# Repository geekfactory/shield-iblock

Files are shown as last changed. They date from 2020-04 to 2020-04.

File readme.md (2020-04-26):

# Shield iBlock

Shield para Arduino Uno R3 (y tarjetas que comparten las mismas dimensiones) que permite conectar módulos y accesorios compatibles con el sistema iBlock desarrollado por Geek Factory.

Este shield "exporta" los puertos de la tarjeta Arduino Uno a cables planos de 10 hilos que pueden usarse para interconectar con otros módulos o el protoboard.

El sistema iBlock esta diseñado para usarse durante el aprendizaje de sistemas digitales programables o para desarrollar aplicaciones finales.

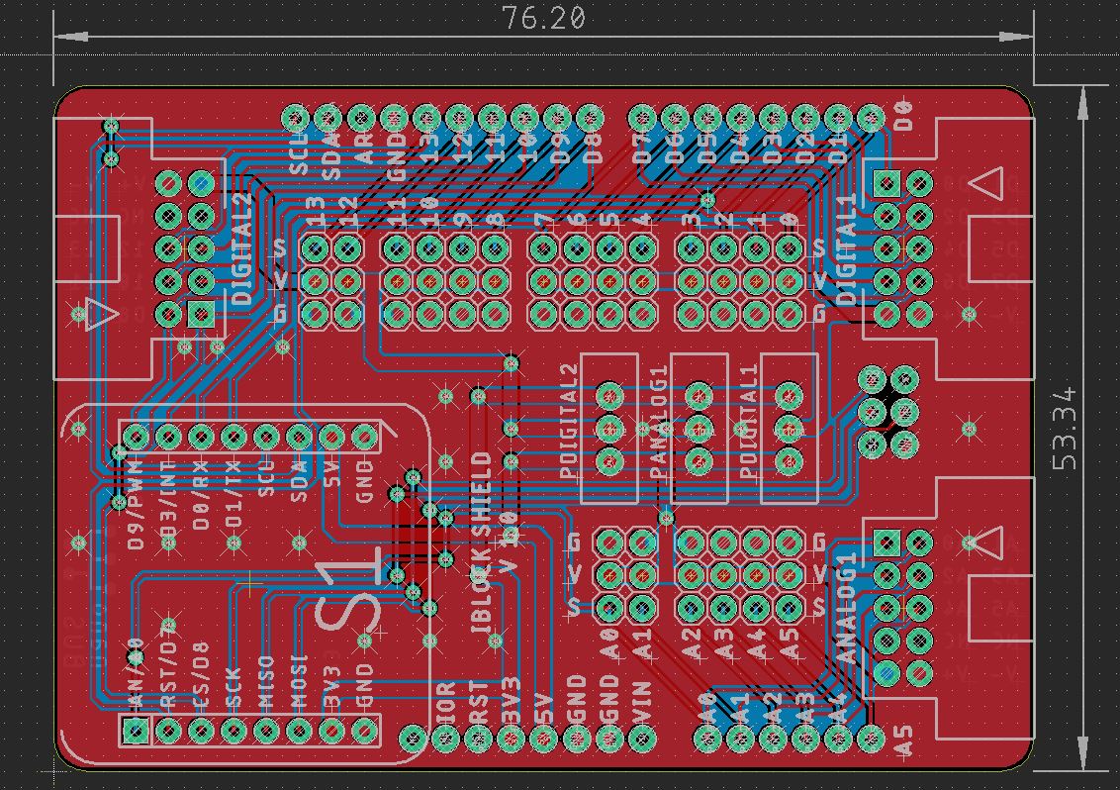
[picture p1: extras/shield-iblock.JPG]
Shield ioBlock


## Sistema iBlock

Se trata de una solución de conectividad diseñada para facilitar la reutilización de hardware en prototipos y sistemas realizados para producción. Esta basada en el uso de conectores [IDC (Insulation Displacement Connector)](https://en.wikipedia.org/wiki/Insulation-displacement_connector) y cable plano.

Principalmente se contempla el uso de conectores de 10 pines que permoiten llevar 8 bits o pines de I/O de propósito general y además la tierra y el voltaje de alimentación.

En este sistema cada uno de los módulos se diseñan con una distribución de pines conocida, de forma que sea posible intercambiar y reutilizar el hardware según las necesidades del proyecto.

La distribución de pines en el conector IDC-10 es la siguiente:

1. D0
2. D1
3. D2
4. D3
5. D4
6. D5
7. D6
8. D7
9. GND
10. V+ (3.3 o 5 volts)

Como el arduino Uno dispone de más puertos digitales, se continua en otro conector:

1. D8
2. D9
3. D10
4. D11
5. D12
6. D13
7. NC (sin conexión)
8. NC (sin conexión)
9. GND
10. V+ (3.3 o 5 volts)

La distribución es similar para los pines analógicos de la tarjeta.

## Periféricos y características

* 3 conectores IDC-10 que exponen todos los puertos digitales y analógicos de la tarjeta arduino
	* DIGITAL1 - Expone los pines del 0 al 7 digitales
	* DIGITAL2 - Expone los pines del 8 al 13 digitales
	* ANALOG1 - Expone los pines A0 al A5 analógicos
* 20 conectores tipo servo que brindan acceso a la alimentación y a todas las señales (D0 - D13 y A0 - A5)
* Diseño apilable que permite colocar otros shields o accesorios arriba de esta placa, incluso el conector SPI (ISP) se replica a otros shields
* Se utilizan conectores IDC-10 en angulo que permite la conexión del cable plano cuando hay otro shield colocado encima
* Selección de voltaje de alimentación (3.3 volts o 5 volts) en cada uno de los conectores IDC-10 mediante interruptores
* Conector Nanobus que permite expandir la funcionalidad del shield con otros módulos desarrollados para este estándar
* Dimensiones del PCB: 76.2 mm x 53.34mm (3 x 2.1 pulgadas)

## Contenido del repositorio

1. __root__ - Archivos fuente de EAGLE para esta placa
2. __/documents__ - Documentación adicional, hojas de datos de componentes e instrucciones de ensamble
3. __/production__ - Histórico de gerbers enviados a producción
4. __/extras__ - Dibujos técnicos, imagehes, hardware de montaje adicional y diseños de accesorios relacionados
4. __/firmware__ - Si existe el firmware de prueba o definitivo de esta placa

## Licencia de uso

**Este proyecto se publica como hardware de codigo abierto. Favor de leer detenidamente el archivo license.md para información detallada de la licencia.**

**Reconocimiento-NoComercial-CompartirIgual 4.0 Internacional (CC BY-NC-SA 4.0)**

Esto es un resumen inteligible para humanos (y no un sustituto) de la licencia.

Usted es libre de:

* __Compartir__ — copiar y redistribuir el material en cualquier medio o formato
* __Adaptar__ — remezclar, transformar y crear a partir del material

El licenciador no puede revocar estas libertades mientras cumpla con los términos de la licencia.

Bajo las condiciones siguientes:

* __Reconocimiento__ — Debe reconocer adecuadamente la autoría, proporcionar un enlace a la licencia e indicar si se han realizado cambios. Puede hacerlo de cualquier manera razonable, pero no de una manera que sugiera que tiene el apoyo del licenciador o lo recibe por el uso que hace.

* __NoComercial__ — No puede utilizar el material para una finalidad comercial.

* __CompartirIgual__ — Si remezcla, transforma o crea a partir del material, deberá difundir sus contribuciones bajo la misma licencia que el original.

No hay restricciones adicionales — No puede aplicar términos legales o medidas tecnológicas que legalmente restrinjan realizar aquello que la licencia permite.

## Versiones del Hardware

* 1.0 - Versión inicial

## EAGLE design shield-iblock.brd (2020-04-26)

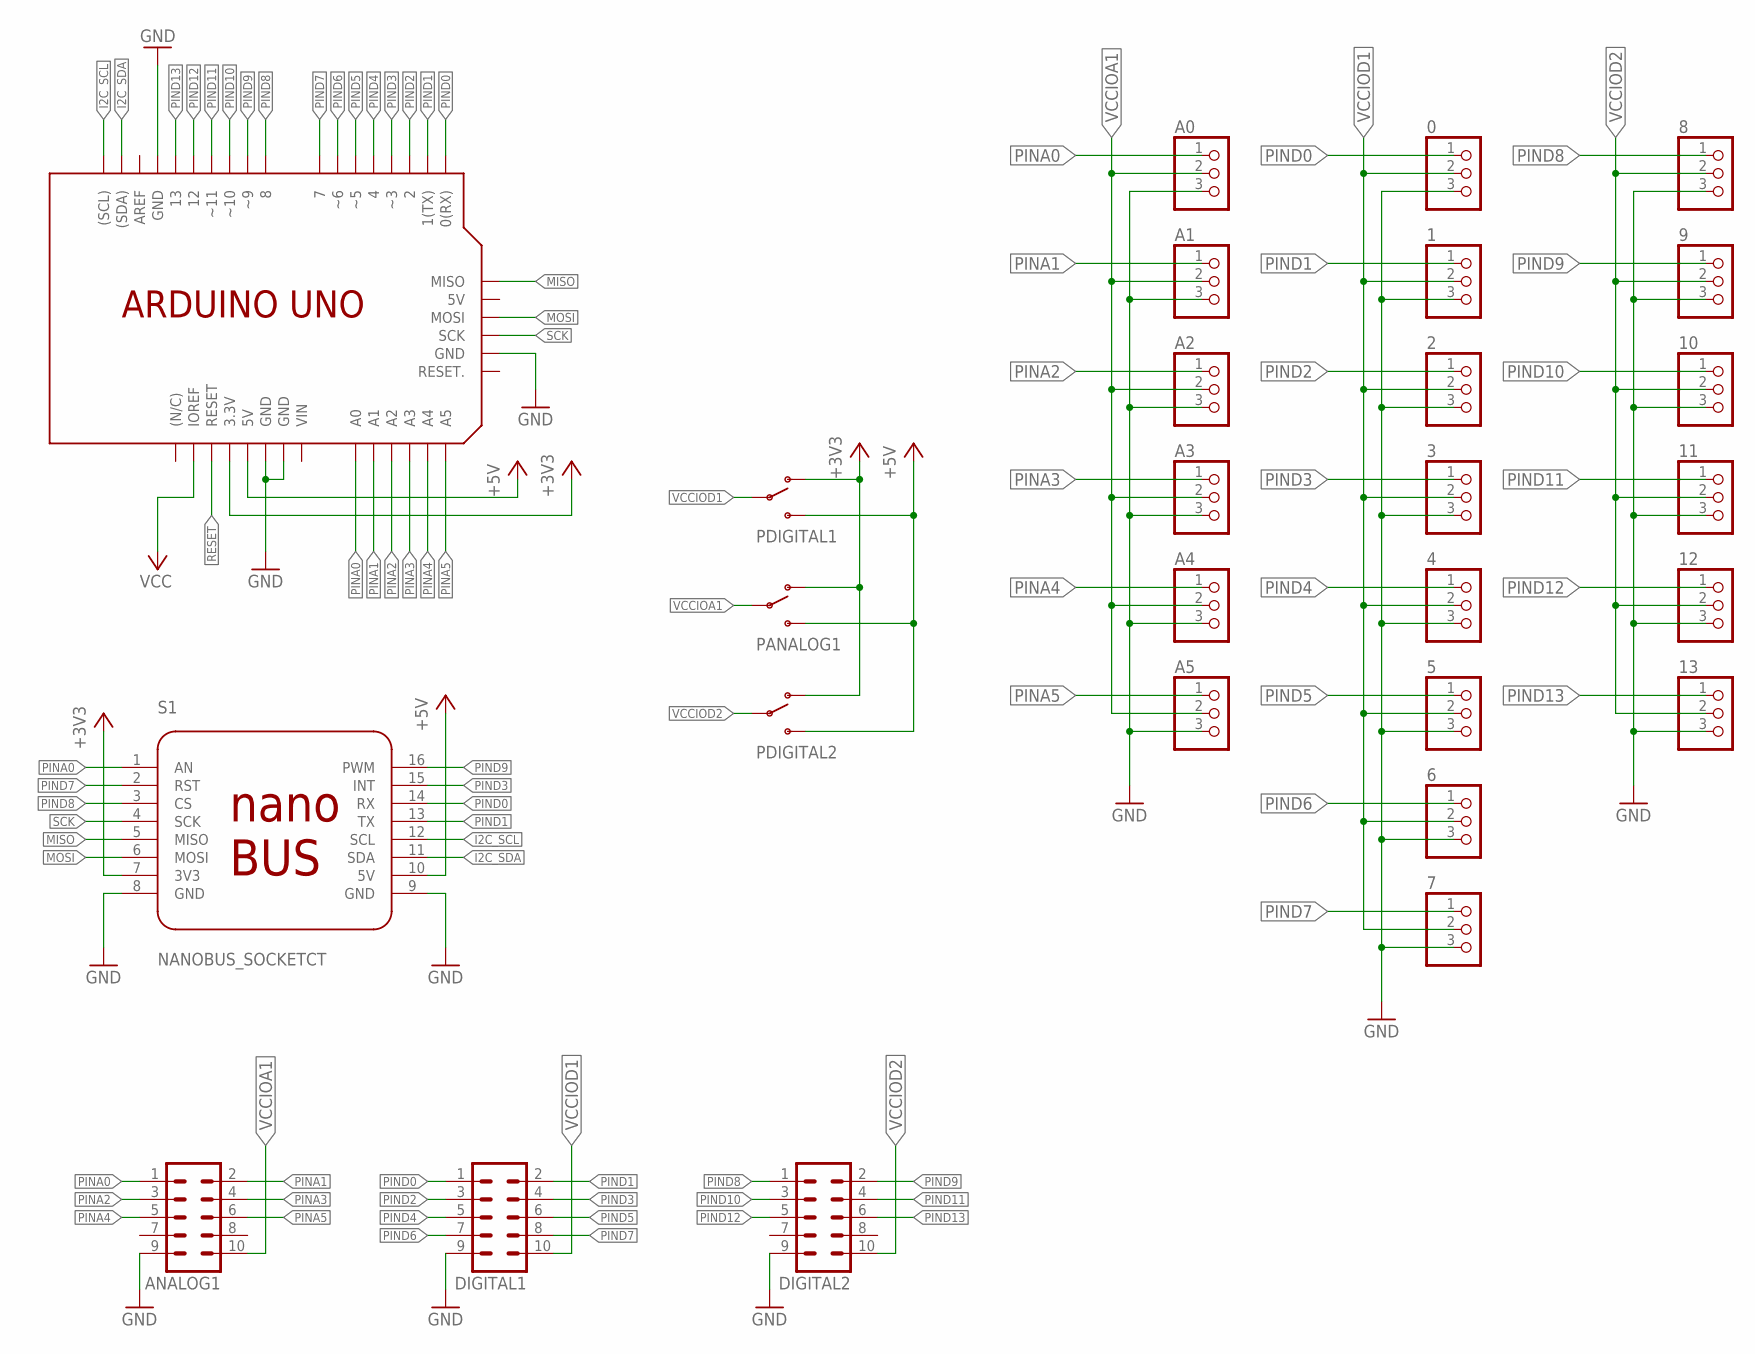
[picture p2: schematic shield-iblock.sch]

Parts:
0, 1, 2, 3, 4, 5, 6, 7, 8, 9, 10, 11, 12, 13: PINHD-1X3; 1X03
A0, A1, A2, A3, A4, A5: PINHD-1X3; 1X03
ANALOG1: MA05-2A
ARDUINO1: ARDUINO_UNO_NHNBR; ARDUINO_UNO_NH_NB_ROUND
DIGITAL1, DIGITAL2: MA05-2A
PANALOG1: SWITCH-SPSTPTH; SWITCH-SPDT
PDIGITAL1, PDIGITAL2: SWITCH-SPSTPTH; SWITCH-SPDT
S1: NANOBUS_SOCKETCT; NANOBUS_CONNECTOR_CLEAR_TOP

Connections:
+3V3: ARDUINO1.3V3 (3.3V), PANALOG1.1 (O), PDIGITAL1.1 (O), PDIGITAL2.1 (O), S1.7 (3V3)
+5V: ARDUINO1.5V, PANALOG1.3 (S), PDIGITAL1.3 (S), PDIGITAL2.3 (S), S1.10 (5V)
GND: 0.3, 1.3, 2.3, 3.3, 4.3, 5.3, 6.3, 7.3, 8.3, 9.3, 10.3, 11.3, 12.3, 13.3, A0.3, A1.3, A2.3, A3.3, A4.3, A5.3, ANALOG1.9, ARDUINO1.GND, ARDUINO1.GND. (GND), ARDUINO1.GND.. (GND), ARDUINO1.GND_ (GND), DIGITAL1.9, DIGITAL2.9, S1.8 (GND), S1.9 (GND)
I2C_SCL: ARDUINO1.SCL ((SCL)), S1.12 (SCL)
I2C_SDA: ARDUINO1.SDA ((SDA)), S1.11 (SDA)
MISO: ARDUINO1.MISO, S1.5 (MISO)
MOSI: ARDUINO1.MOSI, S1.6 (MOSI)
PINA0: A0.1, ANALOG1.1, ARDUINO1.A0, S1.1 (AN)
PINA1: A1.1, ANALOG1.2, ARDUINO1.A1
PINA2: A2.1, ANALOG1.3, ARDUINO1.A2
PINA3: A3.1, ANALOG1.4, ARDUINO1.A3
PINA4: A4.1, ANALOG1.5, ARDUINO1.A4
PINA5: A5.1, ANALOG1.6, ARDUINO1.A5
PIND0: 0.1, ARDUINO1.0 (0(RX)), DIGITAL1.1, S1.14 (RX)
PIND1: 1.1, ARDUINO1.1 (1(TX)), DIGITAL1.2, S1.13 (TX)
PIND2: 2.1, ARDUINO1.2, DIGITAL1.3
PIND3: 3.1, ARDUINO1.3 (~3), DIGITAL1.4, S1.15 (INT)
PIND4: 4.1, ARDUINO1.4, DIGITAL1.5
PIND5: 5.1, ARDUINO1.5 (~5), DIGITAL1.6
PIND6: 6.1, ARDUINO1.6 (~6), DIGITAL1.7
PIND7: 7.1, ARDUINO1.7, DIGITAL1.8, S1.2 (RST)
PIND8: 8.1, ARDUINO1.8, DIGITAL2.1, S1.3 (CS)
PIND9: 9.1, ARDUINO1.9 (~9), DIGITAL2.2, S1.16 (PWM)
PIND10: 10.1, ARDUINO1.10 (~10), DIGITAL2.3
PIND11: 11.1, ARDUINO1.11 (~11), DIGITAL2.4
PIND12: 12.1, ARDUINO1.12, DIGITAL2.5
PIND13: 13.1, ARDUINO1.13, DIGITAL2.6
RESET: ARDUINO1.RST (RESET)
SCK: ARDUINO1.SCK, S1.4 (SCK)
VCC: ARDUINO1.IOR (IOREF)
VCCIOA1: A0.2, A1.2, A2.2, A3.2, A4.2, A5.2, ANALOG1.10, PANALOG1.2
VCCIOD1: 0.2, 1.2, 2.2, 3.2, 4.2, 5.2, 6.2, 7.2, DIGITAL1.10, PDIGITAL1.2
VCCIOD2: 8.2, 9.2, 10.2, 11.2, 12.2, 13.2, DIGITAL2.10, PDIGITAL2.2

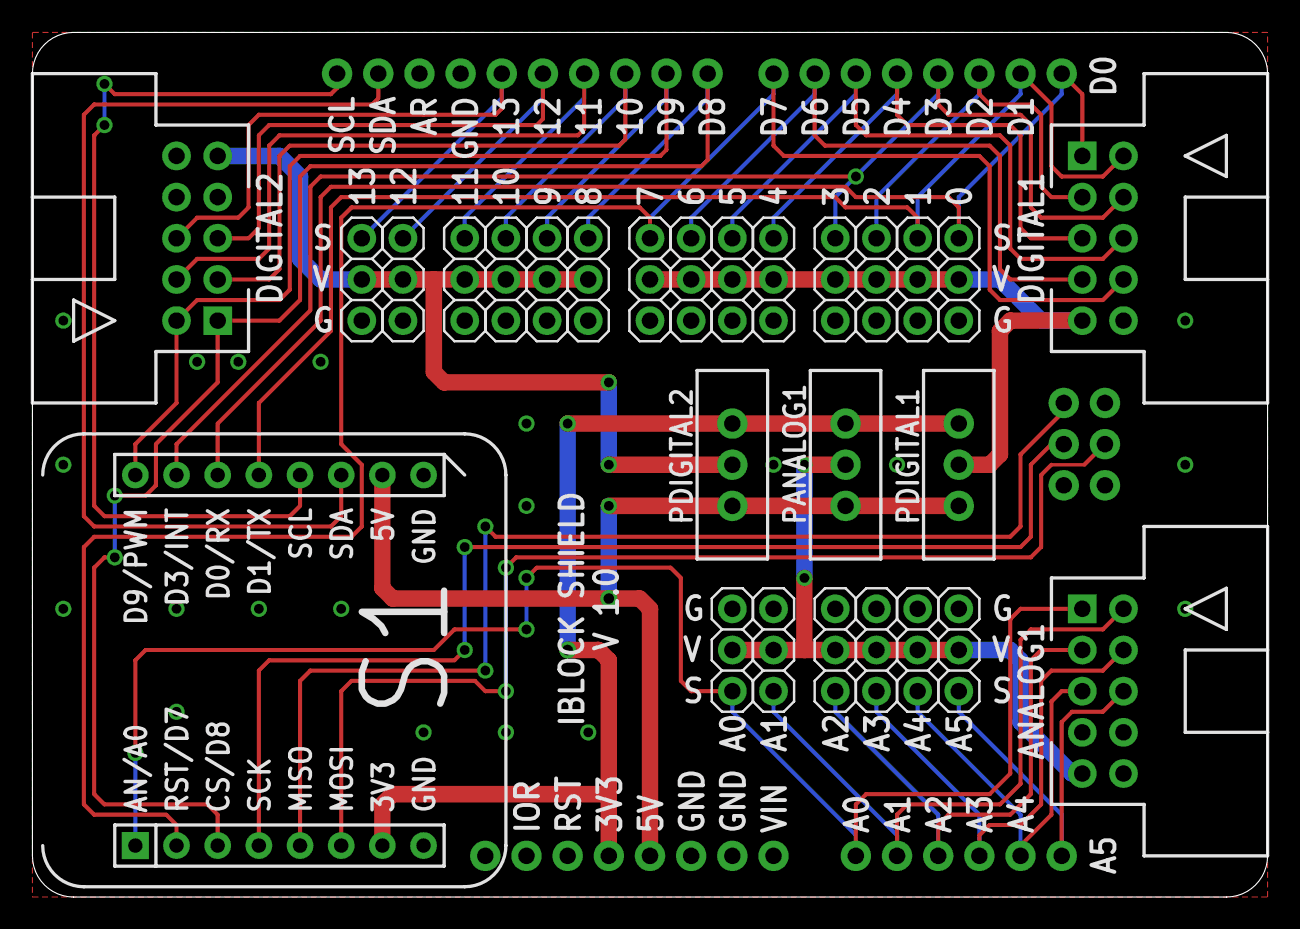
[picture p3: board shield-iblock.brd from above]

Board: 2 copper layers, 76.2 x 53.3 mm, 28 parts (0 on the bottom side), 31 nets.
